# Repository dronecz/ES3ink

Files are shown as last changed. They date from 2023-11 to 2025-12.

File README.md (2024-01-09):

### ES3ink is a board designed to control e-ink displays. 

This repo holds HW and SW (to be done) information for this board.

It can be used with Arduino or [CircuitPython](https://github.com/dronecz/circuitpython).

You can view [schematic](https://kicanvas.org/?github=https%3A%2F%2Fgithub.com%2Fdronecz%2FES3ink%2Fblob%2Fmain%2FHW%2FES3ink.kicad_sch) or [board layout](https://kicanvas.org/?github=https%3A%2F%2Fgithub.com%2Fdronecz%2FES3ink%2Fblob%2Fmain%2FHW%2FES3ink.kicad_pcb) in [KiCanvas](https://kicanvas.org/).

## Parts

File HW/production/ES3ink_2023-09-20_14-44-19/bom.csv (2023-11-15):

Designator | Footprint | Quantity | Value | LCSC Part #
C1, C10, C11, C12, C15, C16, C17, C18, C3, C7, C8, C9 | 0805 | 12 | 1uF
C12.3546, C20, C4, C5 | 0805 | 4 | 10uF
C13 | 0805 | 1 | 100nF
C14, C19, C22 | 0805 | 3 | 4u7F
C21, C6 | 0805 | 2 | 22uF
D1, D2, D3, D5 | D_SOD-123 | 4 | MBR0520LT
D4 | 0805 | 1 | LED
D6 | LED_WS2812B-2020_PLCC4_2.0x2.0mm | 1 | WS2812B
H1, H2 | MountingHole_3.2mm_M3_DIN965_Pad | 2 | MountingHole
J1 | USB_C_Receptacle_HRO_TYPE-C-31-M-12 | 1 | USB_C_Receptacle_USB2.0
J2 | TE_2-1734839-4_1x24-1MP_P0.5mm_Horizontal | 1 | Conn_01x24_Pin
J3 | JST_PH_S2B-PH-SM4-TB_1x02-1MP_P2.00mm_Horizontal | 1 | Conn_01x02_Pin
J4 | JST_SH_SM04B-SRSS-TB_1x04-1MP_P1.00mm_Horizontal | 1 | Conn_01x04_Socket
J5 | USB_C_Receptacle_HRO_TYPE-C-31-M-15 | 1 | USB_C_Receptacle_USB2.0
JP1, JP2, JP3 | SolderJumper-2_P1.3mm_Open_TrianglePad1.0x1.5mm | 3 | SolderJumper_2_Open
L1 | 1812 | 1 | 10uH/1A
Q1, Q3 | SOT-23 | 2 | DMG3415U-7
Q2 | SOT-23 | 1 | SI1308EDL-T1-GE3
Q4 | SOT-23 | 1 | SI2305
R1, R2 | 0805 | 2 | 5K1
R10 | 0805 | 1 | 2R2
R11, R15, R16, R17, R18, R19, R20, R3, R4, R5, R6, R7, R8 | 0805 | 13 | 10K
R12 | 0805 | 1 | 10K | DNP
R13 | 0805 | 1 | 0R
R14 | 0805 | 1 | 1K
R8.8456 | 0805 | 1 | 0,47R
SW1 | SW_Push_1P1T_NO_CK_KMR2 | 1 | RESET
SW2 | SW_Push_1P1T_NO_CK_KMR2 | 1 | BOOT
SW3 | JS202011JCQN | 1 | SW_SPST
U1 | ESP32-S3-WROOM-2 | 1 | ESP32-S3-WROOM-2
U2 | SOT-23-5 | 1 | AP2112K-3.3
U3 | SOT-23-5 | 1 | MCP73831-2-OT

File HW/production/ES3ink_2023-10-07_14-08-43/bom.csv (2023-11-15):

Designator | Footprint | Quantity | Value | LCSC Part #
C1, C10, C11, C12, C15, C16, C17, C18, C3, C7, C8, C9 | 0805 | 12 | 1uF
C13, C4 | 0805 | 2 | 100nF
C14, C19, C22 | 0805 | 3 | 4u7F
C2, C20, C5 | 0805 | 3 | 10uF
C21, C6 | 0805 | 2 | 22uF
D1, D2, D3, D5 | D_SOD-123 | 4 | MBR0520LT
D4 | 0805 | 1 | LED
D6 | LED_WS2812B-2020_PLCC4_2.0x2.0mm | 1 | WS2812B
H1, H2 | MountingHole_3.2mm_M3_DIN965_Pad | 2 | MountingHole
J1 | USB_C_Receptacle_HRO_TYPE-C-31-M-12 | 1 | USB_C_Receptacle_USB2.0
J2 | TE_2-1734839-4_1x24-1MP_P0.5mm_Horizontal | 1 | Conn_01x24_Pin
J3 | JST_PH_S2B-PH-SM4-TB_1x02-1MP_P2.00mm_Horizontal | 1 | Conn_01x02_Pin
J4 | JST_SH_SM04B-SRSS-TB_1x04-1MP_P1.00mm_Horizontal | 1 | Conn_01x04_Socket
J5 | USB_C_Receptacle_HRO_TYPE-C-31-M-15 | 1 | USB_C_Receptacle_USB2.0
JP1, JP2, JP3 | SolderJumper-2_P1.3mm_Open_TrianglePad1.0x1.5mm | 3 | SolderJumper_2_Open
L1 | 1812 | 1 | 10uH/1A
Q1 | SOT-23 | 1 | AO3401A
Q2 | SOT-23 | 1 | SI1308EDL-T1-GE3
Q3 | SOT-23 | 1 | DMP2045U-7
Q4 | SOT-23 | 1 | SI2305
R1, R2 | 0805 | 2 | 5K1
R10 | 0805 | 1 | 2R2
R11, R15, R16, R17, R19, R20, R3, R4, R5, R6, R7, R8 | 0805 | 12 | 10K
R13 | 0805 | 1 | 0R
R14 | 0805 | 1 | 1K
R18 | 0805 | 1 | 1M
R9 | 0805 | 1 | 0,47R
SW1 | SW_Push_1P1T_NO_CK_KMR2 | 1 | RESET
SW2 | SW_Push_1P1T_NO_CK_KMR2 | 1 | BOOT
SW3 | JS202011JCQN | 1 | SW_SPST
U1 | ESP32-S3-WROOM-2 | 1 | ESP32-S3-WROOM-2
U2 | SOT-23-5 | 1 | AP2112K-3.3
U3 | SOT-23-5 | 1 | MCP73831-2-OT

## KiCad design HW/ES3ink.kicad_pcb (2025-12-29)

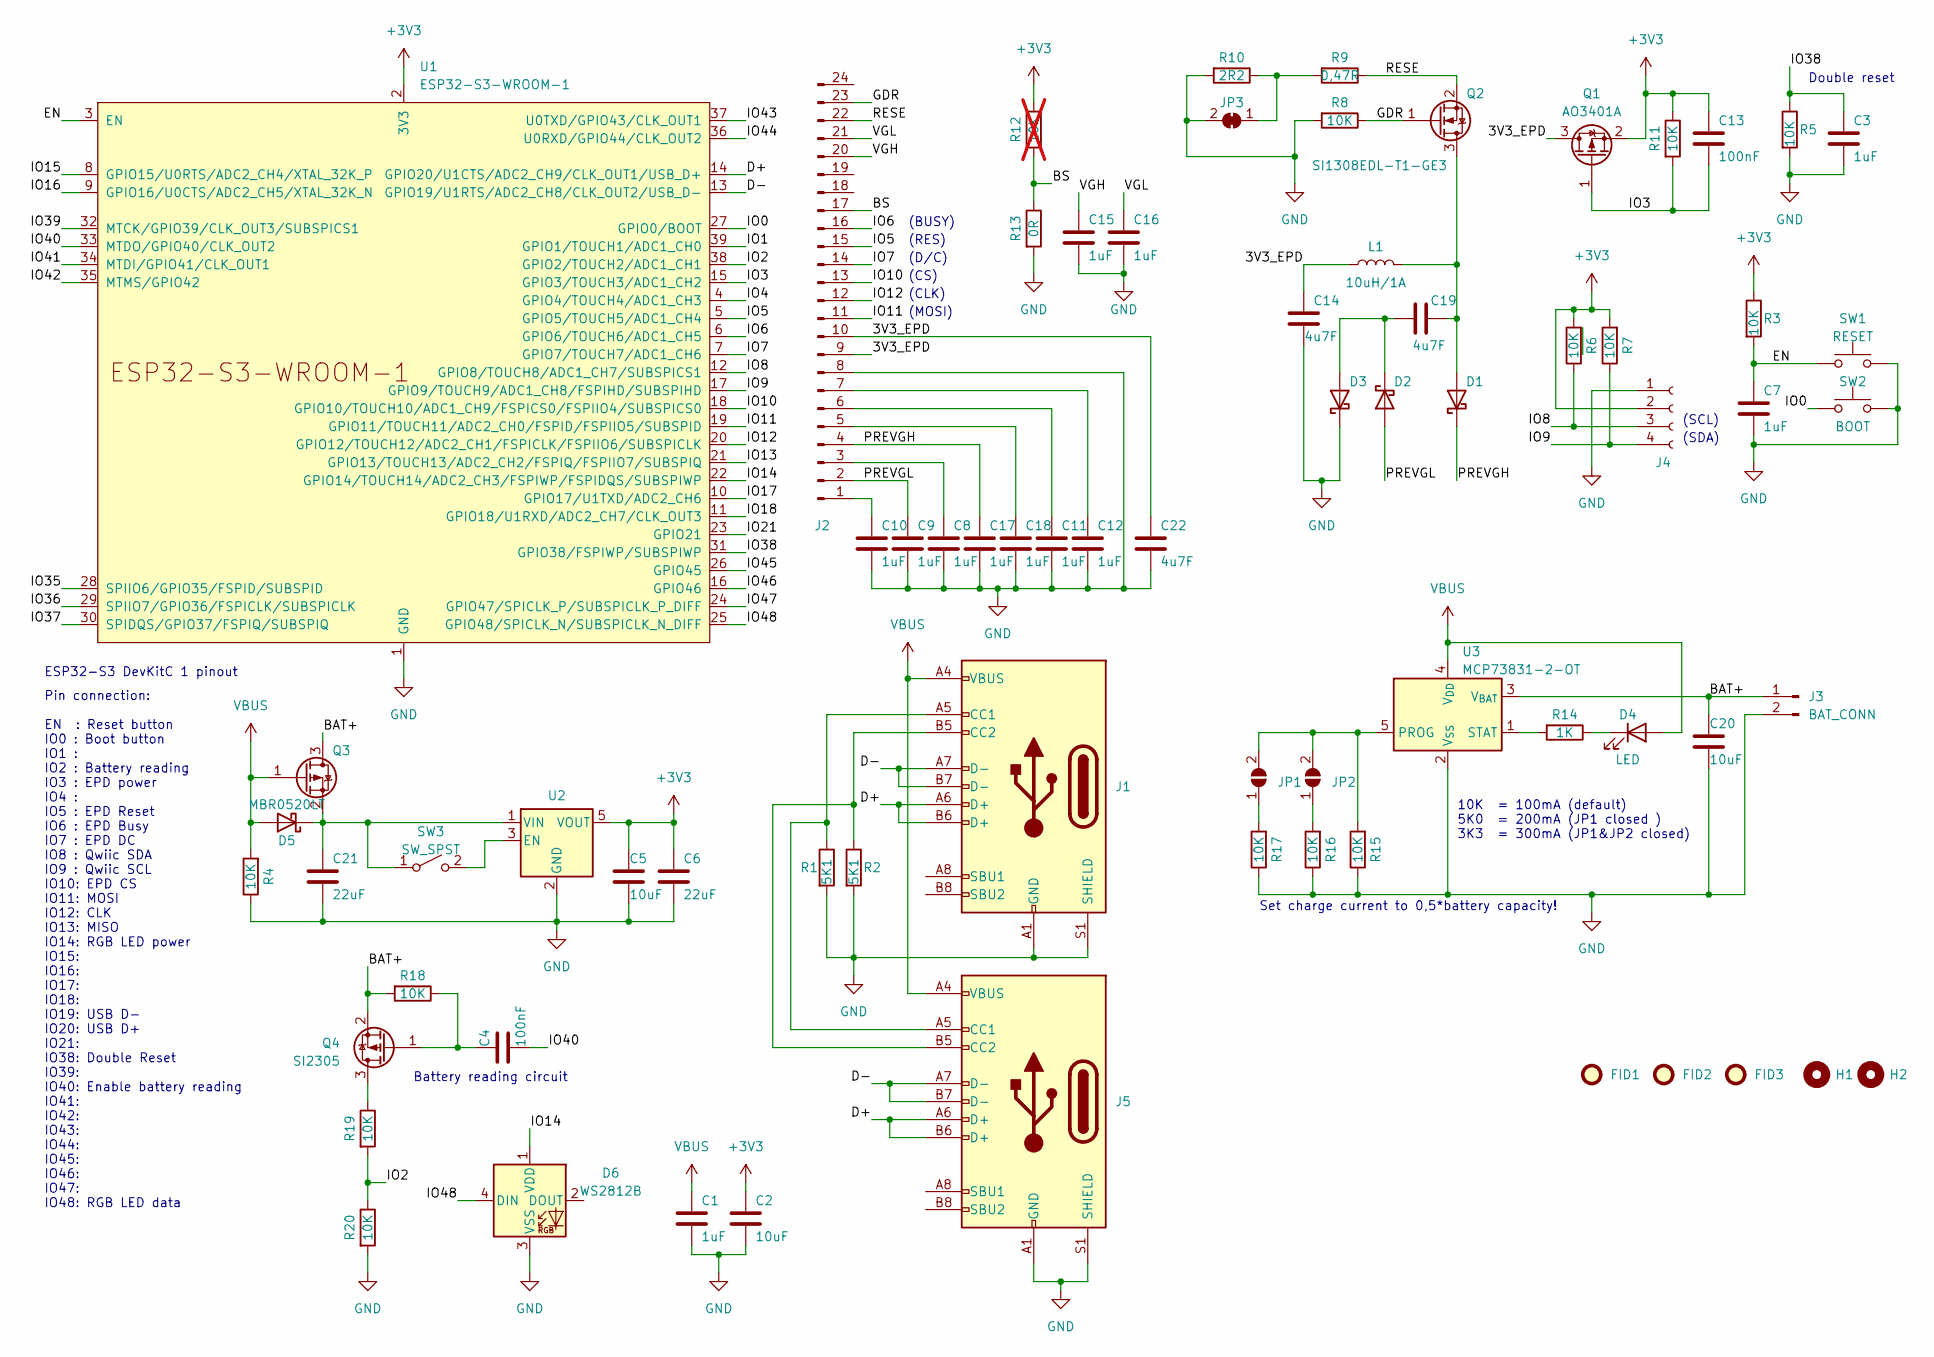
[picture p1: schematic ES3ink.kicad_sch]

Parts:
C1, C3, C7, C8, C9, C10, C11, C12, C15, C16, C17, C18: 1uF; C_0805_2012Metric
C2, C5, C20: 10uF; C_0805_2012Metric
C4, C13: 100nF; C_0805_2012Metric
C6, C21: 22uF; C_0805_2012Metric
C14, C19, C22: 4u7F; C_0805_2012Metric
D1, D2, D3: MBR0530; D_SOD-123
D4: LED; D_0805_2012Metric
D5: MBR0520LT; D_SOD-123
D6: WS2812B; LED_WS2812B-2020_PLCC4_2.0x2.0mm
FID1, FID2, FID3: Fiducial; Fiducial_0.75mm_Mask1.5mm
H1, H2: MountingHole; MountingHole_3.2mm_M3_DIN965_Pad
J1: USB_C_Receptacle_USB2.0; USB_C_Receptacle_HRO_TYPE-C-31-M-12
J2: Conn_01x24_Pin; GCT_FFC2B28-24-G
J3: BAT_CONN; JST_PH_S2B-PH-SM4-TB_1x02-1MP_P2.00mm_Horizontal
J4: Conn_01x04_Socket; JST_SH_SM04B-SRSS-TB_1x04-1MP_P1.00mm_Horizontal
J5: USB_C_Receptacle_USB2.0; USB_C_Receptacle_HRO_TYPE-C-31-M-15
JP1, JP2: SolderJumper_2_Open; SolderJumper-2_P1.3mm_Open_TrianglePad1.0x1.5mm
JP3: SolderJumper_2_Open; SolderJumper-2_P1.3mm_Bridged_RoundedPad1.0x1.5mm
L1: 10uH/1A; L_1812_4532Metric; Mouser LQH43PN100M26L
Q1: AO3401A; SOT-23
Q2: SI1308EDL-T1-GE3; SOT-323_SC-70
Q3: DMP2045U-7; SOT-23
Q4: SI2305; SOT-23
R1, R2: 5K1; R_0805_2012Metric
R3, R4, R5, R6, R7, R8, R11, R15, R16, R17, R18, R19, R20: 10K; R_0805_2012Metric
R9: 0,47R; R_0805_2012Metric
R10: 2R2; R_0805_2012Metric
R12: 10K; R_0805_2012Metric; not fitted
R13: 0R; R_0805_2012Metric
R14: 1K; R_0805_2012Metric
SW1: RESET; SW_Push_1P1T_NO_CK_KMR2
SW2: BOOT; SW_Push_1P1T_NO_CK_KMR2
SW3: SW_SPST; JS202011JCQN
U1: ESP32-S3-WROOM-1
U2: AP2112K-3.3; SOT-23-5
U3: MCP73831-2-OT; SOT-23-5

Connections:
+3V3: C2.1, C5.1, C6.1, C13.1, J4.2, Q1.2 (S), R3.1, R6.2, R7.2, R11.1, R12.1, U1.2 (3V3), U2.5 (VOUT)
/3V3_EPD: C14.1, C22.1, J2.9, J2.10, L1.1, Q1.3 (D)
/BAT+: C20.1, J3.1, Q3.3 (D), Q4.2 (S), R18.2, U3.3 (V_{BAT})
/BS: J2.17, R12.2, R13.1
/D+: J1.A6 (D+), J1.B6 (D+), J5.A6 (D+), J5.B6 (D+), U1.14 (GPIO20/U1CTS/ADC2_CH9/CLK_OUT1/USB_D+)
/D-: J1.A7 (D-), J1.B7 (D-), J5.A7 (D-), J5.B7 (D-), U1.13 (GPIO19/U1RTS/ADC2_CH8/CLK_OUT2/USB_D-)
/EN: C7.1, R3.2, SW1.1, U1.3 (EN)
/GDR: J2.23, Q2.1 (G), R8.1
/IO0: SW2.1, U1.27 (GPIO0/BOOT)
/IO1: U1.39 (GPIO1/TOUCH1/ADC1_CH0)
/IO2: R19.2, R20.1, U1.38 (GPIO2/TOUCH2/ADC1_CH1)
/IO3: C13.2, Q1.1 (G), R11.2, U1.15 (GPIO3/TOUCH3/ADC1_CH2)
/IO4: U1.4 (GPIO4/TOUCH4/ADC1_CH3)
/IO5: J2.15, U1.5 (GPIO5/TOUCH5/ADC1_CH4)
/IO6: J2.16, U1.6 (GPIO6/TOUCH6/ADC1_CH5)
/IO7: J2.14, U1.7 (GPIO7/TOUCH7/ADC1_CH6)
/IO8: J4.3, R6.1, U1.12 (GPIO8/TOUCH8/ADC1_CH7/SUBSPICS1)
/IO9: J4.4, R7.1, U1.17 (GPIO9/TOUCH9/ADC1_CH8/FSPIHD/SUBSPIHD)
/IO10: J2.13, U1.18 (GPIO10/TOUCH10/ADC1_CH9/FSPICS0/FSPIIO4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)
/IO11: J2.11, U1.19 (GPIO11/TOUCH11/ADC2_CH0/FSPID/FSPIIO5/S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)
/IO12: J2.12, U1.20 (GPIO12/TOUCH12/ADC2_CH1/FSPICLK/FSPIIO6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)
/IO13: U1.21 (GPIO13/TOUCH13/ADC2_CH2/FSPIQ/FSPIIO7/S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)
/IO14: D6.1 (VDD), U1.22 (GPIO14/TOUCH14/ADC2_CH3/FSPIWP/FSPIDQS/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)
/IO15: U1.8 (GPIO15/U0RTS/ADC2_CH4/XTAL_32K_P)
/IO16: U1.9 (GPIO16/U0CTS/ADC2_CH5/XTAL_32K_N)
/IO17: U1.10 (GPIO17/U1TXD/ADC2_CH6)
/IO18: U1.11 (GPIO18/U1RXD/ADC2_CH7/CLK_OUT3)
/IO21: U1.23 (GPIO21)
/IO35: U1.28 (SPIIO6/GPIO35/FSPID/SUBSPID)
/IO36: U1.29 (SPIIO7/GPIO36/FSPICLK/SUBSPICLK)
/IO37: U1.30 (SPIDQS/GPIO37/FSPIQ/SUBSPIQ)
/IO38: C3.1, R5.1, U1.31 (GPIO38/FSPIWP/SUBSPIWP)
/IO39: U1.32 (MTCK/GPIO39/CLK_OUT3/SUBSPICS1)
/IO40: C4.2, U1.33 (MTDO/GPIO40/CLK_OUT2)
/IO41: U1.34 (MTDI/GPIO41/CLK_OUT1)
/IO42: U1.35 (MTMS/GPIO42)
/IO43: U1.37 (U0TXD/GPIO43/CLK_OUT1)
/IO44: U1.36 (U0RXD/GPIO44/CLK_OUT2)
/IO45: U1.26 (GPIO45)
/IO46: U1.16 (GPIO46)
/IO47: U1.24 (GPIO47/SPICLK_P/SUBSPICLK_P_DIFF)
/IO48: D6.4 (DIN), U1.25 (GPIO48/SPICLK_N/SUBSPICLK_N_DIFF)
/PREVGH: C17.1, D1.1 (K), J2.4
/PREVGL: C9.1, D2.2 (A), J2.2
/RESE: J2.22, Q2.2 (S), R9.1
/VGH: C15.1, J2.20
/VGL: C16.1, J2.21
GND: C1.2, C2.2, C3.2, C5.2, C6.2, C7.2, C8.2, C9.2, C10.2, C11.2, C12.2, C14.2, C15.2, C16.2, C17.2, C18.2, C20.2, C21.2, C22.2, D3.1 (K), D6.3 (VSS), J1.A1 (GND), J1.A12 (GND), J1.B1 (GND), J1.B12 (GND), J1.S1 (SHIELD), J2.8, J3.2, J4.1, J5.A1 (GND), J5.A12 (GND), J5.B1 (GND), J5.B12 (GND), J5.S1 (SHIELD), JP3.2 (B), R1.2, R2.2, R4.1, R5.2, R8.2, R10.2, R13.2, R15.1, R16.1, R17.1, R20.2, SW1.2, SW2.2, U1.1 (GND), U1.40 (GND), U1.41 (GND), U2.2 (GND), U3.2 (V_{SS})
unnamed: C19.1, D1.2 (A), L1.2, Q2.3 (D)
unnamed: C19.2, D2.1 (K), D3.2 (A)
unnamed: D4.1 (K), R14.1
unnamed: C21.1, D5.1 (K), Q3.2 (S), SW3.1 (A), U2.1 (VIN)
unnamed: J1.A5 (CC1), J5.A5 (CC1), R1.1
unnamed: J1.B5 (CC2), J5.B5 (CC2), R2.1
unnamed: C10.1, J2.1
unnamed: C8.1, J2.3
unnamed: C18.1, J2.5
unnamed: C11.1, J2.6
unnamed: C12.1, J2.7
unnamed: JP1.1 (A), R17.2
unnamed: JP1.2 (B), JP2.2 (B), R15.2, U3.5 (PROG)
unnamed: JP2.1 (A), R16.2
unnamed: JP3.1 (A), R9.2, R10.1
unnamed: Q4.3 (D), R19.1
unnamed: C4.1, Q4.1 (G), R18.1
unnamed: SW3.2 (B), U2.3 (EN)
unnamed: R14.2, U3.1 (STAT)
VBUS: C1.1, D4.2 (A), D5.2 (A), J1.A4 (VBUS), J1.A9 (VBUS), J1.B4 (VBUS), J1.B9 (VBUS), J5.A4 (VBUS), J5.A9 (VBUS), J5.B4 (VBUS), J5.B9 (VBUS), Q3.1 (G), R4.2, U3.4 (V_{DD})

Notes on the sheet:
(RES)
(D/C)
Battery reading circuit
(SCL)
(CLK)
(SDA)
10K = 100mA (default) 5K0 = 200mA (JP1 closed ) 3K3 = 300mA (JP1&JP2 closed)
(BUSY)
Double reset
(MOSI)
Set charge current to 0,5*battery capacity!
Pin connection: EN : Reset button IO0 : Boot button IO1 : IO2 : Battery reading IO3 : EPD power IO4 : IO5 : EPD Reset IO6 : EPD Busy IO7 : EPD DC IO8 : Qwiic SDA IO9 : Qwiic SCL IO10: EPD CS IO11: MOSI IO12: CLK IO13: MISO IO14: RGB LED power IO15: IO16: IO17: IO18: IO19: USB D- IO20: USB D+ IO21: 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
(CS)
ESP32-S3 DevKitC 1 pinout

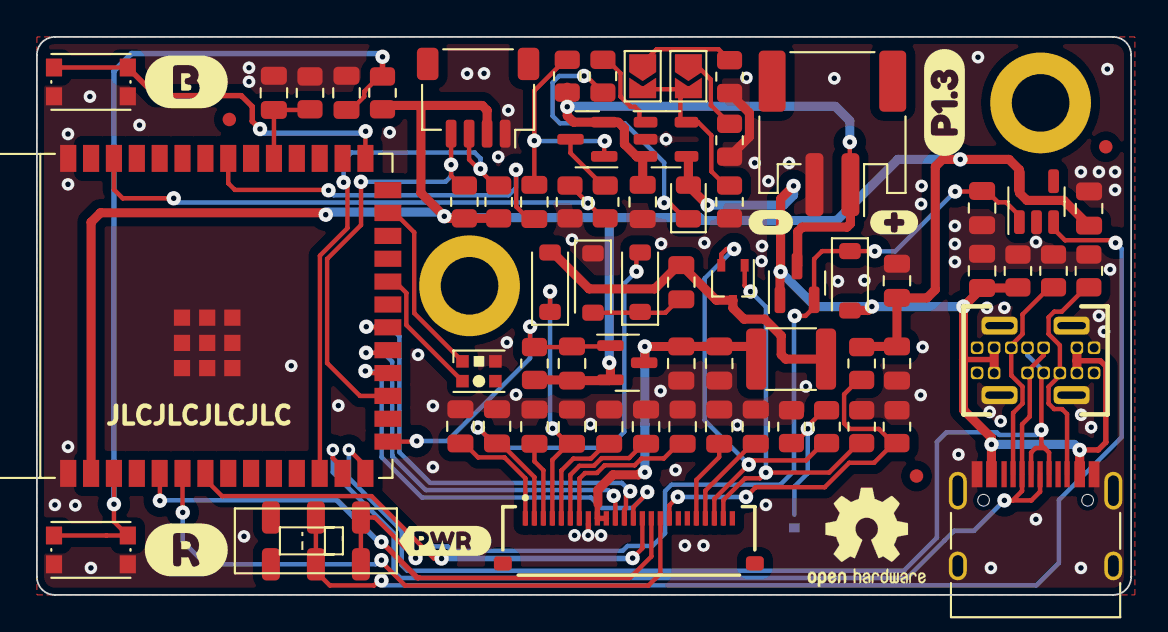
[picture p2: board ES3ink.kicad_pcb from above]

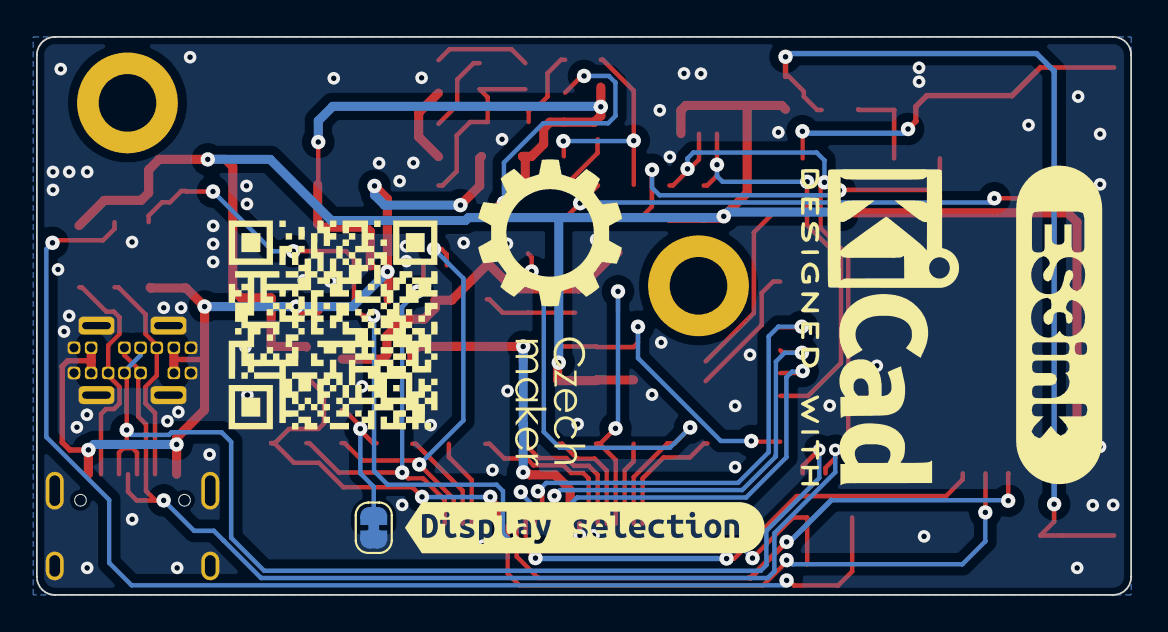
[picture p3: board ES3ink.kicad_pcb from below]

Board: 2 copper layers, 60.8 x 31.0 mm, 80 parts (3 on the bottom side), 49 nets.

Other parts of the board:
kibuzzard-659DC4DE: G***; kibuzzard-659DC4DE
kibuzzard-6951B36D: G***; kibuzzard-6951B36D
kibuzzard-6951C433: G***; kibuzzard-6951C433
kibuzzard-64921EEB: G***; kibuzzard-64921EEB
kibuzzard-64921EFB: G***; kibuzzard-64921EFB
kibuzzard-65272A96: G***; kibuzzard-65272A96
kibuzzard-649216A2: G***; kibuzzard-649216A2
kibuzzard-649216B3: G***; kibuzzard-649216B3

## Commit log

2023-07-11 HW design files upload
    [ES3ink_rev_Bi2_vertical.kicad_pcb, ES3ink_rev_Bi2_vertical.kicad_sch]
2023-07-18 Update
    - renamed files
    - changed schematic to follow Waveshare e-Paper driver HAT
    [ES3ink.kicad_pcb, ES3ink.kicad_sch]
2023-07-18 Removed old files
    [ES3ink_rev_Bi2_vertical.kicad_pcb, ES3ink_rev_Bi2_vertical.kicad_sch]
2023-09-20 Component update
    [ES3ink.kicad_sch]
2023-09-20 Version 2.5 upload
    [ES3ink.kicad_pcb, ES3ink.kicad_sch]
2023-09-20 Layout change & production files
    [ES3ink.kicad_pcb, bom.csv, designators.csv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]
2023-09-29 PCB size increase so it can be manufactured with V-cuts
    [ES3ink.kicad_pcb]
2023-10-03 Update component values
    [ES3ink.kicad_sch]
2023-10-07 Update
    - pin change to match ESP32-S3 DevKitC 1
    - revision change to P1.0 (production)
    [ES3ink.kicad_pcb, ES3ink.kicad_sch, bom.csv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]
2023-10-07 R18 value change
    [ES3ink.kicad_pcb, ES3ink.kicad_sch, bom.csv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]
2023-10-07 Update
    - fix I2C pin at Qwiic connector
    - fix SPI CLK pin for EPD
    [ES3ink.kicad_pcb, ES3ink.kicad_sch]
2023-10-24 Update
    - component value change
    - FPC connector changed to double side connection
    - version increase to 1.1
    [ES3ink.kicad_pcb, ES3ink.kicad_sch, bom.csv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]
2023-11-15 Add title in schematic
    [ES3ink.kicad_sch]
2024-01-09 Update to P1.2
    - changed e-ink pwr pin to IO3
    - unified reference text values
    - add link to view design in KiCanvas
    - version increment to P1.2
    [ES3ink.kicad_pcb, ES3ink.kicad_sch]
2024-01-09 Update ES3ink.kicad_pcb
    - disable visibility of some values
    [ES3ink.kicad_pcb]
2024-05-27 Update
    - changed format to KiCad 8
    - changed some tracks
    - add JP3 label
    - add OHW logo
    [ES3ink.kicad_pcb, ES3ink.kicad_sch]
2025-12-29 Update
    - upgrade to KiCad 9
    - changed U1 from ESP32-S3-WROOM-2 to WROOM-1
    - added 3D models to project
    - added fiducials
    - changed routing of the board
    [ES3ink.kicad_pcb, ES3ink.kicad_sch]
